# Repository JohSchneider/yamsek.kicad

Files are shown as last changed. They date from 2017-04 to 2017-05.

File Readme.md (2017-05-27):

Yet another Modular split ergonomic Keybard
Find build documentation at the Hackaday.io site for [Yet another Modular split ergonomic Keyboard](https://hackaday.io/project/21164-yamsek)

##### matrix_
denote breakout boards that directly connect to the keyboard matrix

##### i2c_bridge_
are boards connecting to each other via external connectors (TRRS at
the moment) and handle i2c buffering, ESD protection, current limiting (primary)
and reverse polarity protection (secondary)

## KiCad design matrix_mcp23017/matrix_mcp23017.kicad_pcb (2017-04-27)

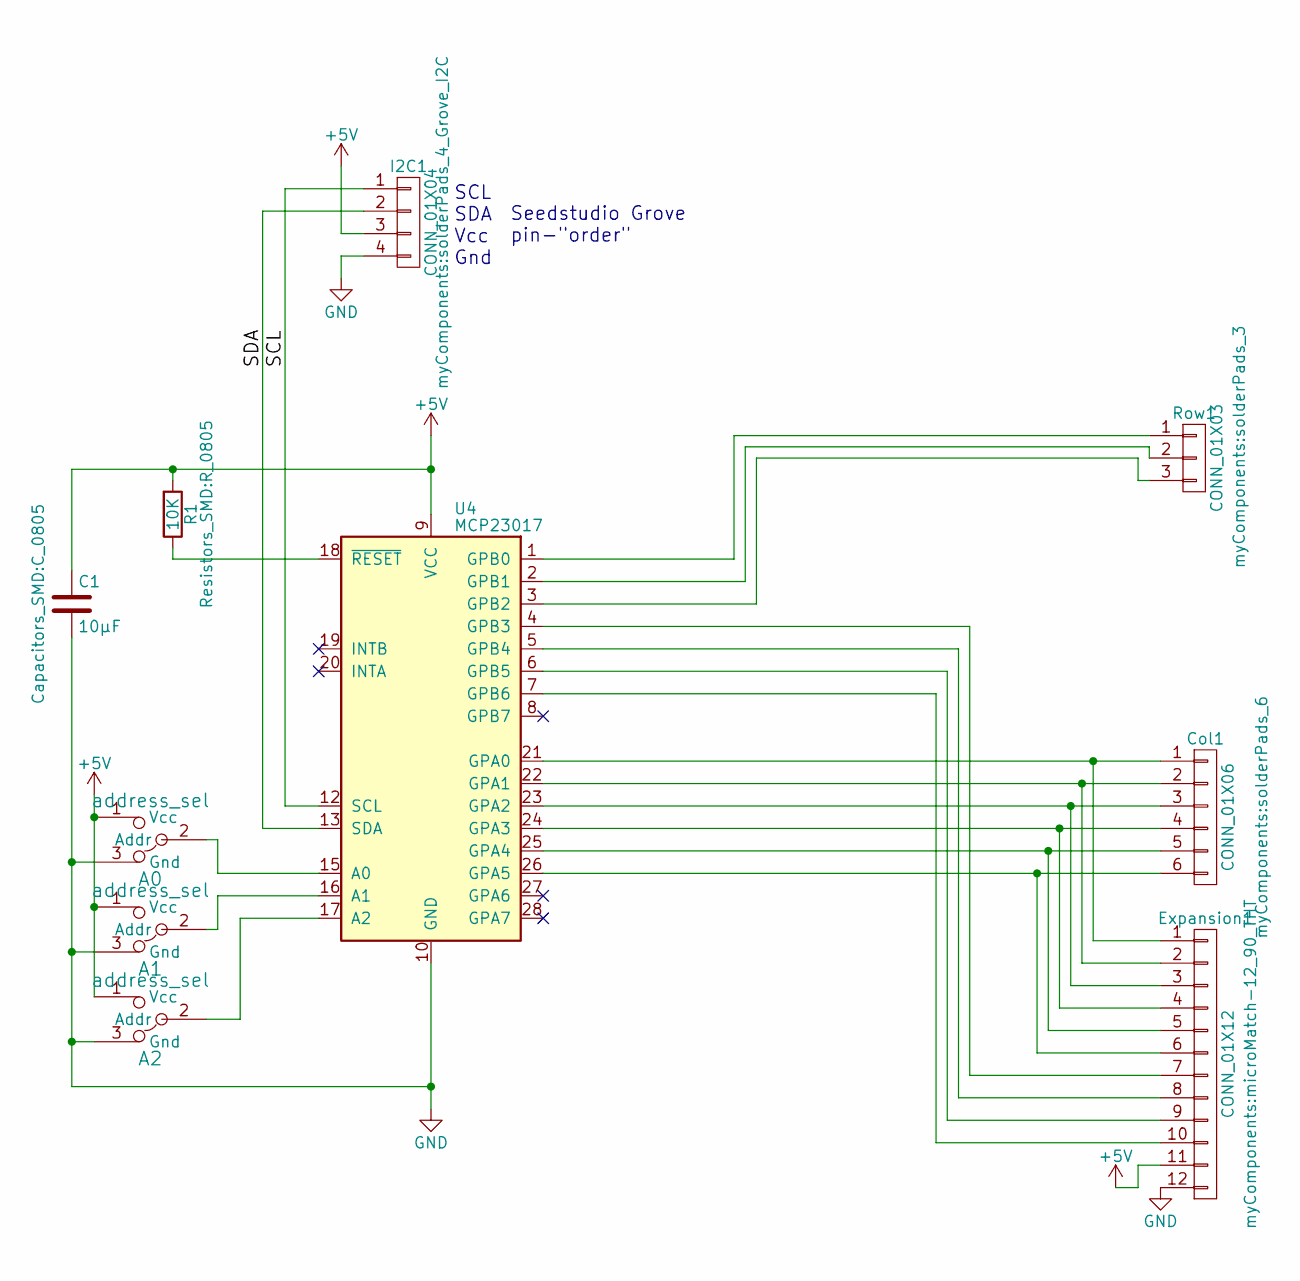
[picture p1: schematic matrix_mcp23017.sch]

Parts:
A0, A1, A2: address_sel; addr_jumper
C1: 10µF; C_0805
Col1: CONN_01X06; solderPads_6
Expansion1: CONN_01X12; microMatch-12_90_THT
I2C1: CONN_01X04; solderPads_4_Grove_I2C
R1: 10K; R_0805
Row1: CONN_01X03; solderPads_3
U4: MCP23017; SOIC-28W_7.5x17.9mm_Pitch1.27mm

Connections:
+5V: A0.1 (Vcc), A1.1 (Vcc), A2.1 (Vcc), C1.1, Expansion1.11, I2C1.3, R1.2, U4.9 (VCC)
/SCL: I2C1.1, U4.12 (SCL)
/SDA: I2C1.2, U4.13 (SDA)
GND: A0.3 (Gnd), A1.3 (Gnd), A2.3 (Gnd), C1.2, Expansion1.12, I2C1.4, U4.10 (GND)
unnamed: A0.2 (Addr), U4.15 (A0)
unnamed: A1.2 (Addr), U4.16 (A1)
unnamed: A2.2 (Addr), U4.17 (A2)
unnamed: Col1.1, Expansion1.1, U4.21 (GPA0)
unnamed: Col1.2, Expansion1.2, U4.22 (GPA1)
unnamed: Col1.3, Expansion1.3, U4.23 (GPA2)
unnamed: Col1.4, Expansion1.4, U4.24 (GPA3)
unnamed: Col1.5, Expansion1.5, U4.25 (GPA4)
unnamed: Col1.6, Expansion1.6, U4.26 (GPA5)
unnamed: Expansion1.7, U4.4 (GPB3)
unnamed: Expansion1.8, U4.5 (GPB4)
unnamed: Expansion1.9, U4.6 (GPB5)
unnamed: Expansion1.10, U4.7 (GPB6)
unnamed: R1.1, U4.18 (~RESET)
unnamed: Row1.1, U4.1 (GPB0)
unnamed: Row1.2, U4.2 (GPB1)
unnamed: Row1.3, U4.3 (GPB2)

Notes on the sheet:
SCL SDA Vcc Gnd
Seedstudio Grove pin-"order"

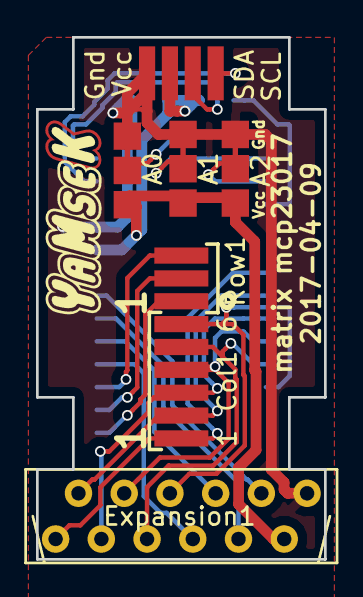
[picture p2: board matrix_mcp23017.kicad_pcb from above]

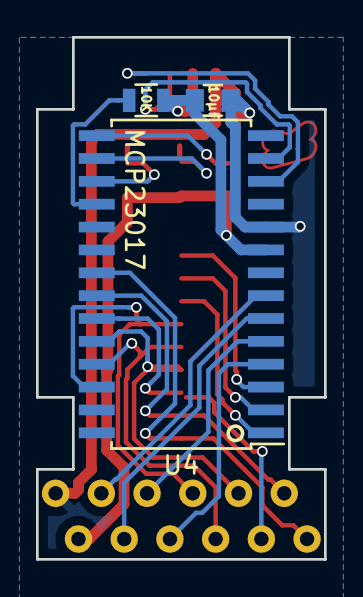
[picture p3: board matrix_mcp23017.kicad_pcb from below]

Board: 2 copper layers, 16.0 x 29.0 mm, 11 parts (3 on the bottom side), 21 nets.

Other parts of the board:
svg2mod: G***; logo

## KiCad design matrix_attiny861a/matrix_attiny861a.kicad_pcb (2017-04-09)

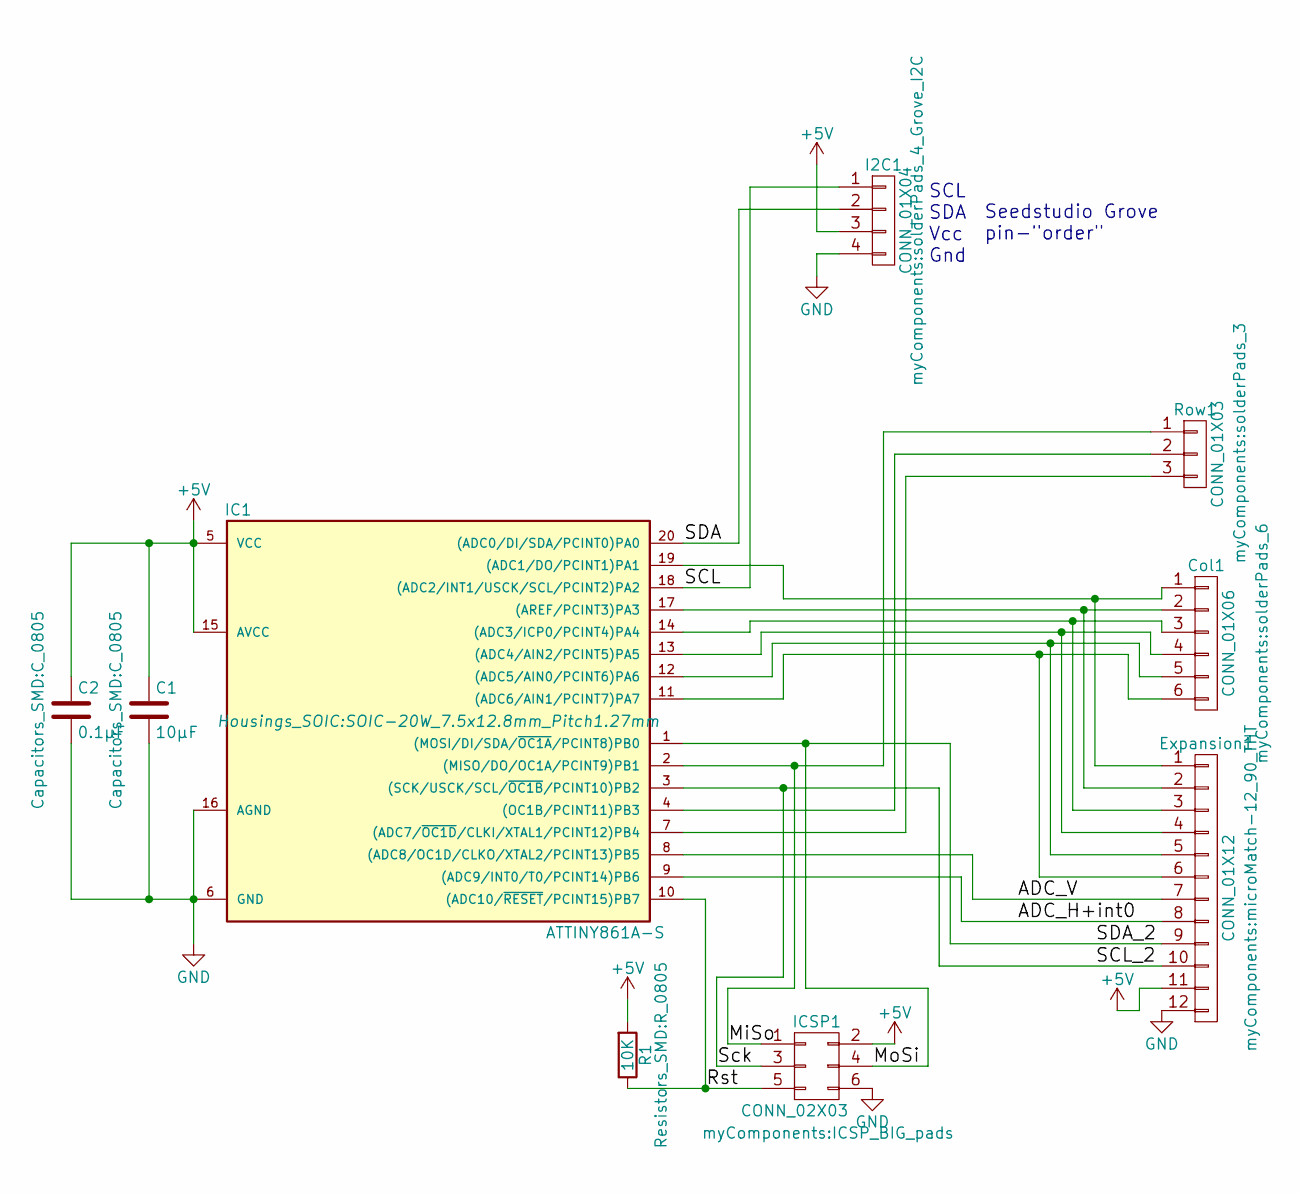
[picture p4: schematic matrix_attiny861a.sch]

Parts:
C1: 10µF; C_0805
C2: 0.1µF; C_0805
Col1: CONN_01X06; solderPads_6
Expansion1: CONN_01X12; microMatch-12_90_THT
I2C1: CONN_01X04; solderPads_4_Grove_I2C
IC1: ATTINY861A-S; SOIC-20W_7.5x12.8mm_Pitch1.27mm
ICSP1: CONN_02X03; ICSP_BIG_pads
R1: 10K; R_0805
Row1: CONN_01X03; solderPads_3

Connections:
+5V: C1.1, C2.1, Expansion1.11, I2C1.3, IC1.5 (VCC), IC1.15 (AVCC), ICSP1.2, R1.2
/ADC_H+int0: Expansion1.8, IC1.9 ((ADC9/INT0/T0/PCINT14)PB6)
/ADC_V: Expansion1.7, IC1.8 ((ADC8/OC1D/CLKO/XTAL2/PCINT13)PB5)
/MiSo: IC1.2 ((MISO/DO/OC1A/PCINT9)PB1), ICSP1.1, Row1.1
/MoSi: Expansion1.9, IC1.1 ((MOSI/DI/SDA/~OC1A~/PCINT8)PB0), ICSP1.4
/Rst: IC1.10 ((ADC10/~RESET~/PCINT15)PB7), ICSP1.5, R1.1
/SCL: I2C1.1, IC1.18 ((ADC2/INT1/USCK/SCL/PCINT2)PA2)
/SCL_2: Expansion1.10, IC1.3 ((SCK/USCK/SCL/~OC1B~/PCINT10)PB2), ICSP1.3
/SDA: I2C1.2, IC1.20 ((ADC0/DI/SDA/PCINT0)PA0)
GND: C1.2, C2.2, Expansion1.12, I2C1.4, IC1.6 (GND), IC1.16 (AGND), ICSP1.6
unnamed: Col1.1, Expansion1.1, IC1.19 ((ADC1/DO/PCINT1)PA1)
unnamed: Col1.2, Expansion1.2, IC1.17 ((AREF/PCINT3)PA3)
unnamed: Col1.3, Expansion1.3, IC1.14 ((ADC3/ICP0/PCINT4)PA4)
unnamed: Col1.4, Expansion1.4, IC1.13 ((ADC4/AIN2/PCINT5)PA5)
unnamed: Col1.5, Expansion1.5, IC1.12 ((ADC5/AIN0/PCINT6)PA6)
unnamed: Col1.6, Expansion1.6, IC1.11 ((ADC6/AIN1/PCINT7)PA7)
unnamed: IC1.4 ((OC1B/PCINT11)PB3), Row1.2
unnamed: IC1.7 ((ADC7/~OC1D~/CLKI/XTAL1/PCINT12)PB4), Row1.3

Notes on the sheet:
SCL SDA Vcc Gnd
Seedstudio Grove pin-"order"

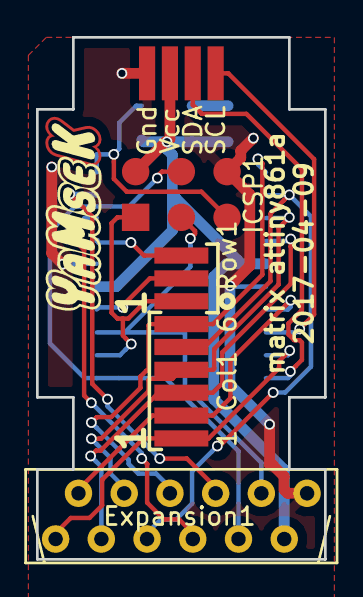
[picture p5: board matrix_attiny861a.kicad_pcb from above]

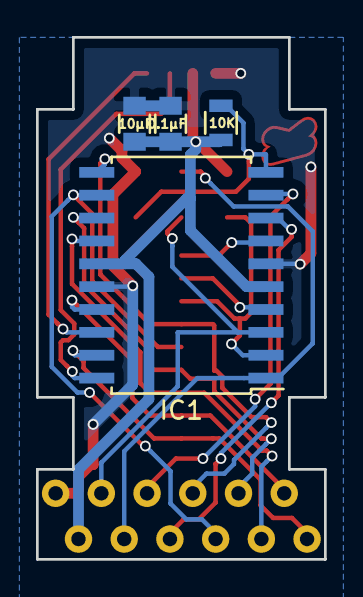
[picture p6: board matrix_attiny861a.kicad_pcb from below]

Board: 2 copper layers, 16.0 x 29.0 mm, 10 parts (4 on the bottom side), 18 nets.

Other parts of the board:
svg2mod: G***; logo

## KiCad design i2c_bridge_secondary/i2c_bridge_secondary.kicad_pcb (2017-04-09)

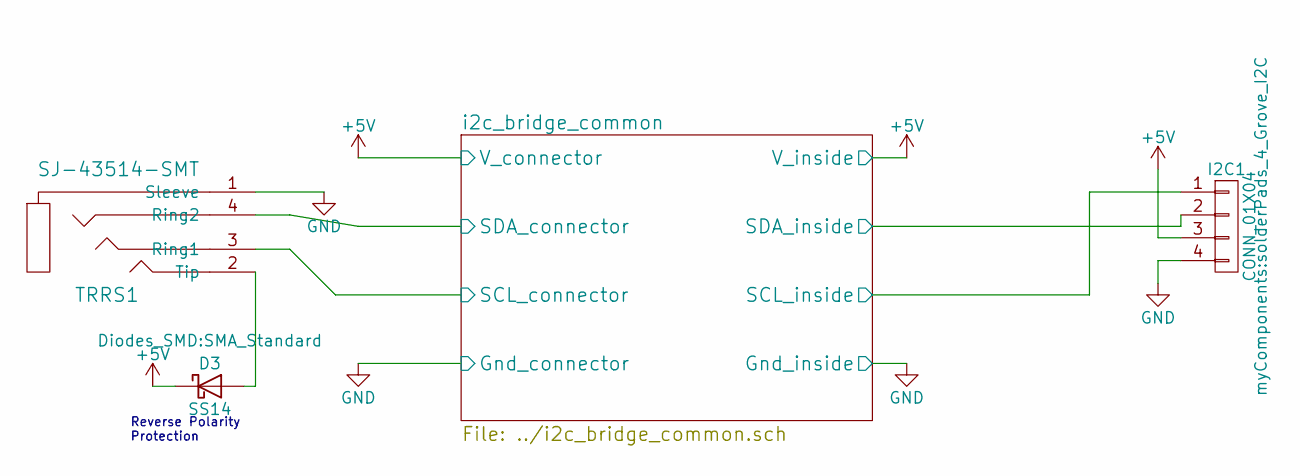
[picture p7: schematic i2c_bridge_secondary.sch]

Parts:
D3: SS14; SMA_Standard
I2C1: CONN_01X04; solderPads_4_Grove_I2C
TRRS1: SJ-43514-SMT; audio_smd_SJ-43514-SMT

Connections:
+5V: D3.1 (K), I2C1.3; also elsewhere on the board
/i2c_bridge_common/SCL_connector: TRRS1.3 (Ring1); also elsewhere on the board
/i2c_bridge_common/SCL_inside: I2C1.1; also elsewhere on the board
/i2c_bridge_common/SDA_connector: TRRS1.4 (Ring2); also elsewhere on the board
/i2c_bridge_common/SDA_inside: I2C1.2; also elsewhere on the board
GND: I2C1.4, TRRS1.1 (Sleeve); also elsewhere on the board
unnamed: D3.2 (A), TRRS1.2 (Tip)

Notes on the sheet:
Reverse Polarity Protection

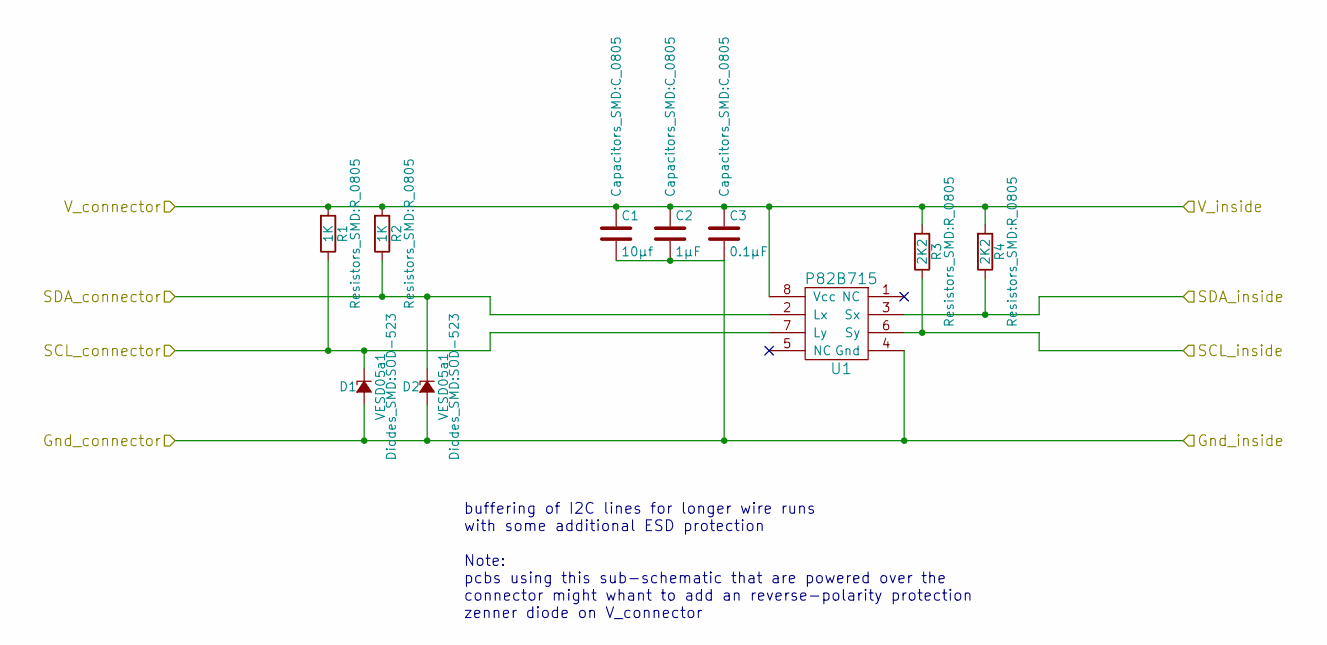
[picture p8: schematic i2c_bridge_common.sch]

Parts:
C1: 10µf; C_0805
C2: 1µF; C_0805
C3: 0.1µF; C_0805
D1, D2: VESD05a1; SOD-523
R1, R2: 1K; R_0805
R3, R4: 2K2; R_0805
U1: P82B715; SOIC-8-N

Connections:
+5V: C1.1, C2.1, C3.1, R1.2, R2.2, R3.2, R4.2, U1.8 (Vcc); also elsewhere on the board
/i2c_bridge_common/SCL_connector: D1.1 (K), R1.1, U1.7 (Ly); also elsewhere on the board
/i2c_bridge_common/SCL_inside: R3.1, U1.6 (Sy); also elsewhere on the board
/i2c_bridge_common/SDA_connector: D2.1 (K), R2.1, U1.2 (Lx); also elsewhere on the board
/i2c_bridge_common/SDA_inside: R4.1, U1.3 (Sx); also elsewhere on the board
GND: C1.2, C2.2, C3.2, D1.2 (A), D2.2 (A), U1.4 (Gnd); also elsewhere on the board

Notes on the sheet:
buffering of I2C lines for longer wire runs with some additional ESD protection Note: pcbs using this sub-schematic that are powered over the connector might whant to add an reverse-polarity protection zenner diode on V_connector

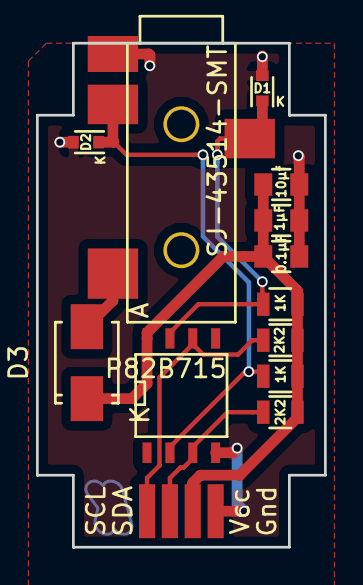
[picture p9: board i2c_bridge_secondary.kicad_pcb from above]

Board: 2 copper layers, 16.0 x 28.0 mm, 14 parts (1 on the bottom side), 7 nets.

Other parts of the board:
svg2mod: G***; logo

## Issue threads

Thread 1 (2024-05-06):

Support Request: QMK firmware for split keyboard with RP2040+MCP23017/18?

azhizhinov, 2024-05-06:
Hello.
I've recreated this keyboard from [this](https://github.com/JohSchneider/yamsek.kicad/files/15220771/sparrow62-v2.0.5-schematic.pdf) and tried to port the QMK firmware.
Original author of this keyboard has the [KMK firmware](https://github.com/74th/sparrow62-kmk), but I failed to get the keyboard running.
I have almost zero knowledge about C-code, so I've tied to the code form various keyboards with the MCP23017/8 on board with no luck.
Left part of this keyboard is working, but can't receive any keycodes from the right part.
I've tried to reuse firmware from the Ferris split keyboard, but there are no keycodes from the right half.
Thanks in advance.

JohSchneider, 2024-05-11:
the left part has the MCU/atmega(?) and the right part is the i2c-ioexpancer=mxp23017?
things to check:
- i2c pullups?
- power rails ok? (check with multimeter, maybe add capacitors near the ioexpander)
- qmk debugging helps
- if the main mcu is an atmega32, flash sth that lets you directly check if the i2c device answers at all - e.g. https://github.com/chatelao/MiniPirate/

azhizhinov, 2024-05-11:
Hello.
Thanks for your attention.
It's the RPi Pico on the left half and MCP23017 on the left.
Pullups? Resistor? It's looks like that.
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
I've checked for 3.3V at 9 and 10 pins, it's defenetly there.
There ara few firmwares with different MCUs + MCP23017/18, but not for the RP2040 as MCU.
I've tried to adopt the [Ferris 2.0](https://github.com/qmk/qmk_firmware/tree/master/keyboards/ferris/0_2) firmware, the [Torn](https://github.com/qmk/qmk_firmware/tree/master/keyboards/torn) firmware, [Ingrained](https://github.com/qmk/qmk_firmware/tree/master/keyboards/ingrained) firmware, but non of them worked in my case.
I've scratched my head against the code [here](https://github.com/azhizhinov/qmk_firmware/tree/sprow63/keyboards/sprow63)? with this code the left half is workin with delays between keypresses.
I'm not a coder at all, the C code is kind of abracadabra for me. :-)
[20240511.SPROW63.00.pdf](https://github.com/JohSchneider/yamsek.kicad/files/15283691/20240511.SPROW63.00.pdf)

azhizhinov, 2024-05-11:
All these firmwares are with "print" commands and I can compile this with "CONSOLE_ENABLE".

azhizhinov, 2024-05-12:
Hello.
Yes, pin 9 = 3.3V, pin 10 = GND.
Could you, please, explain me pullup resistors.
So, these are pullups, right?
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
So, here should be zeroes, right?
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

azhizhinov, 2024-05-12:
> qmk_firmware/tree/master/keyboards/handwired/onekey/keymaps/i2c_scanner

I'm trying to use this firmware and don't understand, should I add #define I2C1_SCL_PIN GP13 and #define I2C1_SDA_PIN GP12? How this i2c_scanner will find an expander without this information?

JohSchneider, 2024-05-13:
'up' is usually the supply voltage, and 'down' is Gnd
btw - there are other good examples and 'reference' schematics
https://learn.adafruit.com/adafruit-mcp23017-i2c-gpio-expander

> So here should be zeroes, right?

depends... what have you set the port a and port b to put out? which port is supposed to drive the matrix high (either rows or columns... depends on your wiring), which ports are supposed to read/scan the matrix? (again: either rows or columns)
those pull-downs you encircled are on port a (GPA0 etc)

>  How this i2c_scanner will find an expander without this information?

you have to configure the i2c to match your wiring; and since rp2040 can mux pins almost everywhere... :-)

azhizhinov, 2024-05-13:
Hello.
I've compiled onekey/i2c_scanner, flashed, but it always says "No I2C device found".
I've checked wiring with multi-meter - GPIO12 (SDA) at MCU is connected to SDA (13) at MCP and GPIO13 (SCL) at MCU is connected to SCK (12) at MCP. Don't understand why the MCP can't be found.

azhizhinov, 2024-05-13:
Finally. :-)
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

azhizhinov, 2024-05-13:
> depends... what have you set the port a and port b to put out? which port is supposed to drive the matrix high (either rows or columns... depends on your wiring), which ports are supposed to read/scan the matrix? (again: either rows or columns) those pull-downs you encircled are on port a (GPA0 etc)
Your keyboard is ROW2COL, but in my case, it's COL2ROW, so GPBs are output and GPAs are input. If I correctly understand this picture.

JohSchneider, 2024-05-13:
again the unpopular answer: "depends" ;-)
depends on how you wire up your key-matrix, implement the matrix scanning, ..., ...
the ioexpander itself doesn't care much about row2col or not; you just have to implement it in the matrix scanning code according to how you wire things up - follow the signal path through one switch+diode and keep the external pull-downs in mind

JohSchneider, 2024-07-07:
closing, since there where no follow up questions

Closed 2024-07-07.

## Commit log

2017-04-07 version control the growinb board family
    [I2C_bridge.sch, attiny861a_breakout.kicad_pcb, attiny861a_breakout.sch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]
2017-04-07 single board slave for the attiny was phased out in favour of split slave+breakout scheme
    [i2c_attiny861a.kicad_pcb, i2c_attiny861a.sch]
2017-04-07 more spacious slave design, matching the main-power board outline
    [i2c_minimal_slave.kicad_pcb]
2017-04-07 added pcb baks to ignore
2017-04-08 switched reset pullups from 2K2 to 10K
    [attiny861a_breakout.kicad_pcb, attiny861a_breakout.sch, mcp23017_breakout.kicad_pcb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]
2017-04-08 more fixes :-s
    [attiny861a_breakout.kicad_pcb, i2c_main_power.kicad_pcb, i2c_minimal_slave.kicad_pcb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]
2017-04-09 move to a more consistens nameing scheme
    matrix_ parts denote breakout boards that directly connect to the keyboard
    matrix
    i2c_bridge are boards connecting to each other via external connectors (TRRS at
    the moment) and handle i2c buffering, ESD protection, current limiting (primary)
    and reverse polarity protection (secondary)
    [i2c_bridge_primary.kicad_pcb, i2c_bridge_primary.sch, i2c_bridge_secondary.kicad_pcb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]
2017-04-09 rename of i2c_bridge_common
    [i2c_bridge_common.sch, i2c_bridge_primary.kicad_pcb, i2c_bridge_primary.sch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]
2017-04-09 added YamseK logo :-)
    [i2c_bridge_primary.kicad_pcb, i2c_bridge_secondary.kicad_pcb, matrix_attiny861a.kicad_pcb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]
2017-04-09 tweaks to the logo
    [i2c_bridge_primary.kicad_pcb, i2c_bridge_secondary.kicad_pcb, matrix_attiny861a.kicad_pcb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]
2017-04-09 bugfixes preparing first order to oshpark
    [matrix_attiny861a.kicad_pcb, matrix_attiny861a.sch, matrix_mcp23017.kicad_pcb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]
2017-04-27 added pin-1 marking on back silkscreen for the MCP23017
    [matrix_mcp23017.kicad_pcb]
